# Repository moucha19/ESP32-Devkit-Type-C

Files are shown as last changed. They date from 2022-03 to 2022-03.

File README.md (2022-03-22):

ESP32 Devkit Type C
===================

## 2022 Update ([*@moucha19*](https://github.com/moucha19))

First of all, I would like to thank the original author for his work. I wanted to make this DevKit as soon as I saw it. However, there were some issues that I thought needed fixing. For example, some components were unavailable or not up-to-date. Here is a full list of my updates that all together make revision **EC**:

* CH340G was changed to CH340C to remove the need for external crystal. I also noticed that it's powered from VBUS, which according to datasheet means that the data lines will run on 5 volts. This might not kill ESP32 right away, but from what I read, it isn't good.
* I replaced MP2359 with MP2259, because the former is not recommended for new designs. JLCPCB still has MP2359s, but I wanted this update to last a while.
* USB-C connector was changed to TYPE-C-31-M-12, which I already had home. Push buttons were also changed for the same reason, but in my opinion they look good and are also pretty common.
* Inductor was replaced with currently available part 
* Some components were moved around to avoid unnecesary DRC errors
* I made pads around ESP32 larger for easier manual soldering, since I don't intend to use SMT assembly service. However, I still generated files for those who do. Use [SMT BOM](jlcpcb/bom_jlc_smt.csv) in the order to get only recommended parts (no USB-C, buttons or headers).
* Project was upgraded to Kicad 6.0

# Description

This PCB is a USB Type C enabled ESP32 development board. It is pin-compatible
with the ESP32 Devkit C but sports a slightly decreased width to fit on a
standard breadboard.  

# Features

* USB Type C
* pin-compatible with ESP32 Devkit
* fits on standard breadboard
* onboard antenna
* jumper to short USB protection diode

Furthermore this board is optimized for JLCPCB assembly, a Chinese SMT PCB
assembly service. All components on this board, except the USB Type C connector,
the push buttons and the pin headers can be assembled by them for around ~$8
including PCB manufacturing and components.

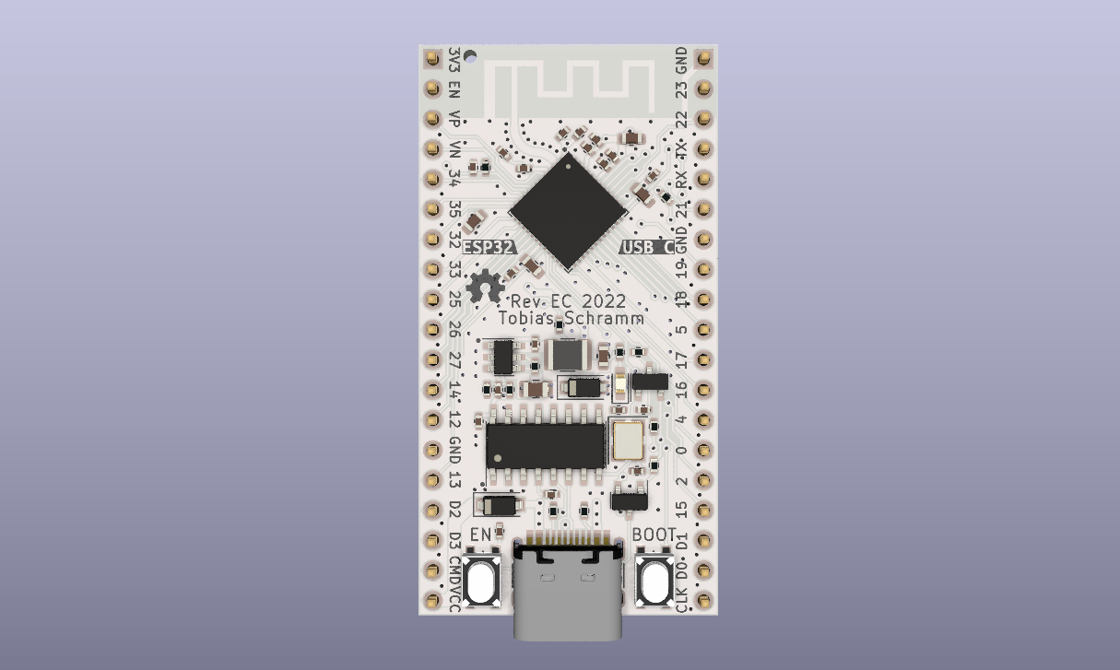
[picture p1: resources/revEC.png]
Devkit


# Assembly

There is an
[interactive HTML BOM](https://htmlpreview.github.io/?https://github.com/moucha19/ESP32-Devkit-Type-C/blob/master/docs/ibom.html)
to help you assemble the board.

Assuming you are using JLCPCB SMT assembly you will need to populate just the
following parts by hand:

| Reference  | Description | LCSC |
|---|---|---|
| J1 | USB Type C connector | [C165948](https://www.lcsc.com/product-detail/USB-Type-C_Korean-Hroparts-Elec-TYPE-C-31-M-12_C165948.html) |
| SW1, SW2 | RESET/BOOT push button | [C589212](https://lcsc.com/product-detail/Tactile-Switches_RI-SHENG-ST-1188_C589212.html) |
| J2, J3 | Pin headers | [C2337](https://lcsc.com/product-detail/Pin-Header-Female-Header_BOOMELE-Boom-Precision-Elec-2-54mm-1x40P_C2337.html) |

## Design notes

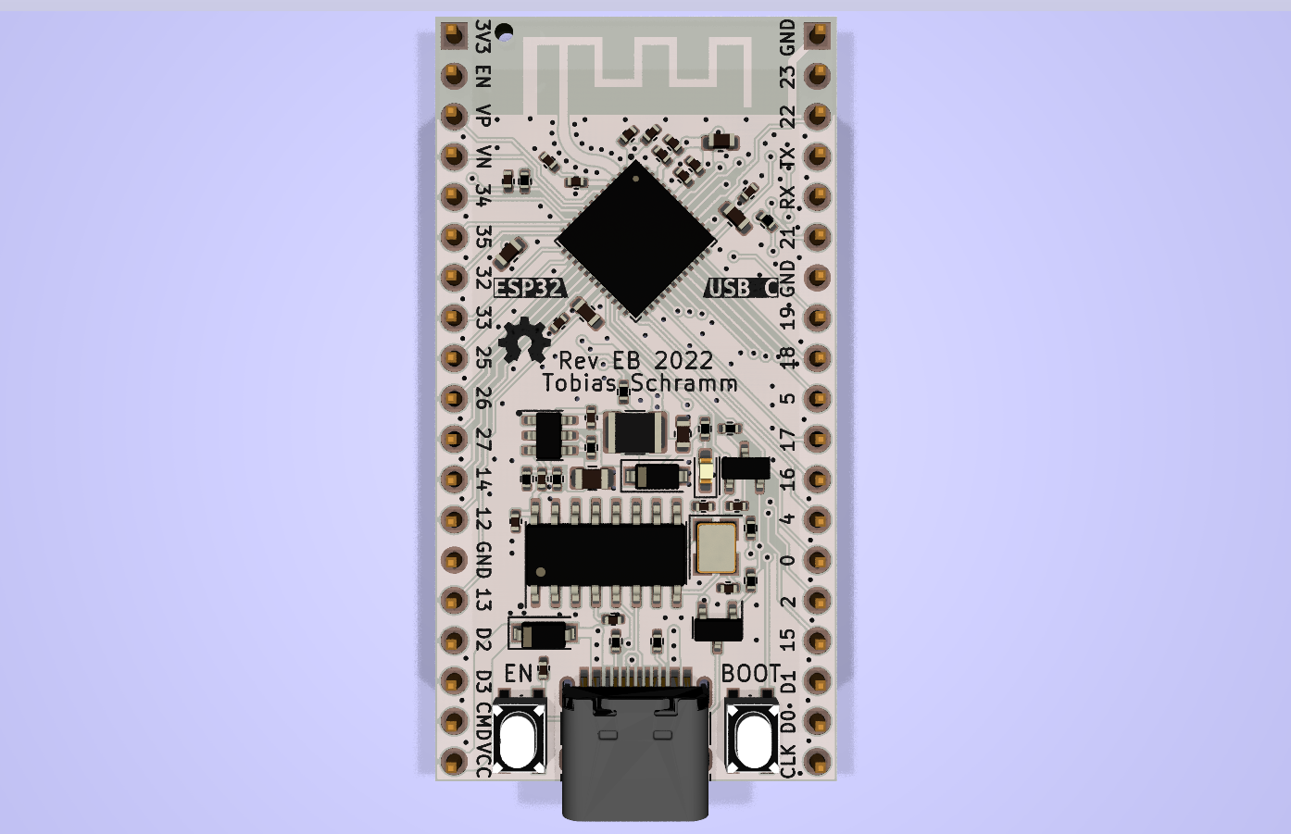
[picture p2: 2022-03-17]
resources/revEB.png

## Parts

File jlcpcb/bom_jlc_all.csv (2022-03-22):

Comment | Designator | Footprint | LCSC Part #
10 nF | C1 | Capacitor_SMD:C_0402_1005Metric | C15195
1uF | C12 | Capacitor_SMD:C_0402_1005Metric | C52923
10uF | C19,C20,C21,C22 | Capacitor_SMD:C_0402_1005Metric | C15525
22 pF | C2,C4 | Capacitor_SMD:C_0402_1005Metric | C1555
10uF | C23,C25 | Capacitor_SMD:C_0603_1608Metric | C19702
10 uF | C3 | Capacitor_SMD:C_0805_2012Metric | C15850
100 nF | C5,C6,C7,C14,C15,C16,C17,C18 | Capacitor_SMD:C_0402_1005Metric | C1525
22 uF | C8,C13,C24 | Capacitor_SMD:C_0603_1608Metric | C59461
B5819W | D1,D2 | Diode_SMD:D_SOD-123 | C8598
LED | D3 | LED_SMD:LED_0603_1608Metric_Castellated | C2286
USB_C_Receptacle_USB2.0 | J1 | Connector_USB:USB_C_Receptacle_HRO_TYPE-C-31-M-12 | C165948
Conn_01x19 | J2,J3 | Connector_PinHeader_2.54mm:PinHeader_1x19_P2.54mm_Vertical
4.7 uH | L1 | Inductor_SMD:L_1210_3225Metric | C90319
SS8050 | Q1,Q2 | Package_TO_SOT_SMD:SOT-23 | C2150
100 kR | R1,R10 | Resistor_SMD:R_0402_1005Metric | C25741
5.1 kR | R2,R3 | Resistor_SMD:R_0402_1005Metric | C25905
330 R | R4,R11,R12 | Resistor_SMD:R_0402_1005Metric | C25104
56kR | R5 | Resistor_SMD:R_0402_1005Metric | C25796
18 kR | R6 | Resistor_SMD:R_0402_1005Metric | C25762
5.1kR | R7,R8,R9 | Resistor_SMD:R_0402_1005Metric | C25905
EN | SW1 | Moucha_Primitives:SW_Push_1P1T_Vertical_3x4mm | C589212
BOOT | SW2 | Moucha_Primitives:SW_Push_1P1T_Vertical_3x4mm | C589212
MP2259 | U1 | Package_TO_SOT_SMD:SOT-23-6 | C82266
CH340C | U2 | Package_SO:SOIC-16_3.9x9.9mm_P1.27mm | C84681
ESP32-PICO-D4 | U3 | Package_ESP32:ESP32-Pico-D4-Thermal | C193707
12MHz | Y1 | Crystal:Crystal_SMD_3225-4Pin_3.2x2.5mm | C9002

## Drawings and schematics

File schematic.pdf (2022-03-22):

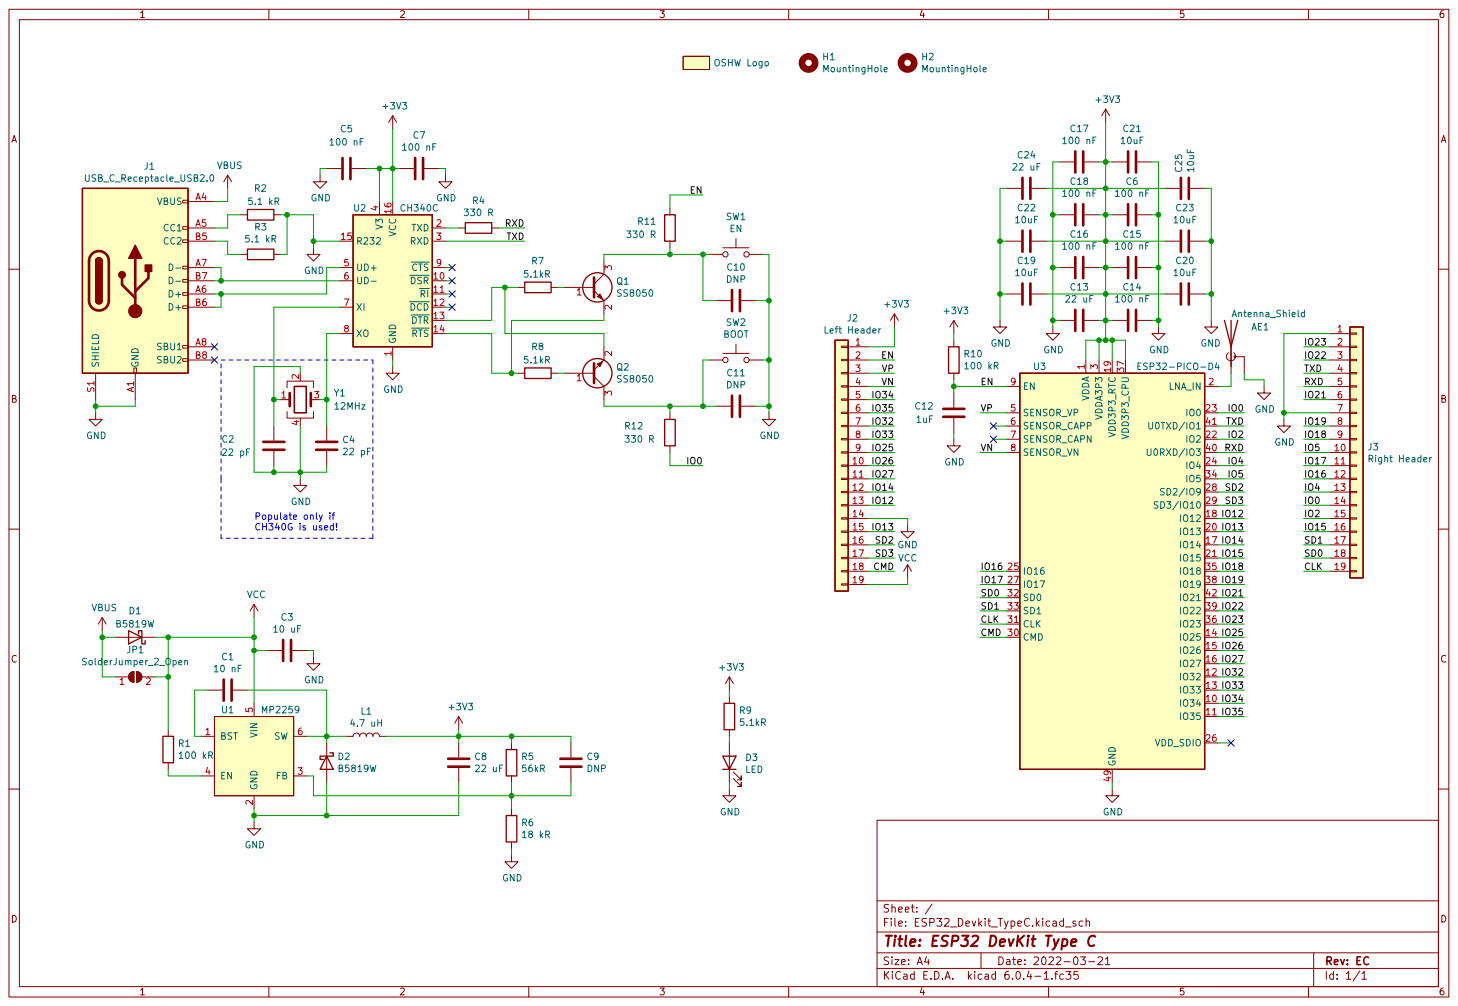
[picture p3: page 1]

4 UD+ 5 UD- 6 XI 7 XO 8 ~{CTS} 9 U2 CH340CGND

1 ~{DSR}10 ~{RI}11 ~{DCD}12 ~{DTR}13 ~{RTS}14 R232 15 VCC 16 TXD 2 RXD 3 V3

IO18 Populate only if CH340G is used!

File: ESP32_Devkit_TypeC.kicad_sch Sheet: /
Id: 1/1 Title: ESP32 DevKit Type C

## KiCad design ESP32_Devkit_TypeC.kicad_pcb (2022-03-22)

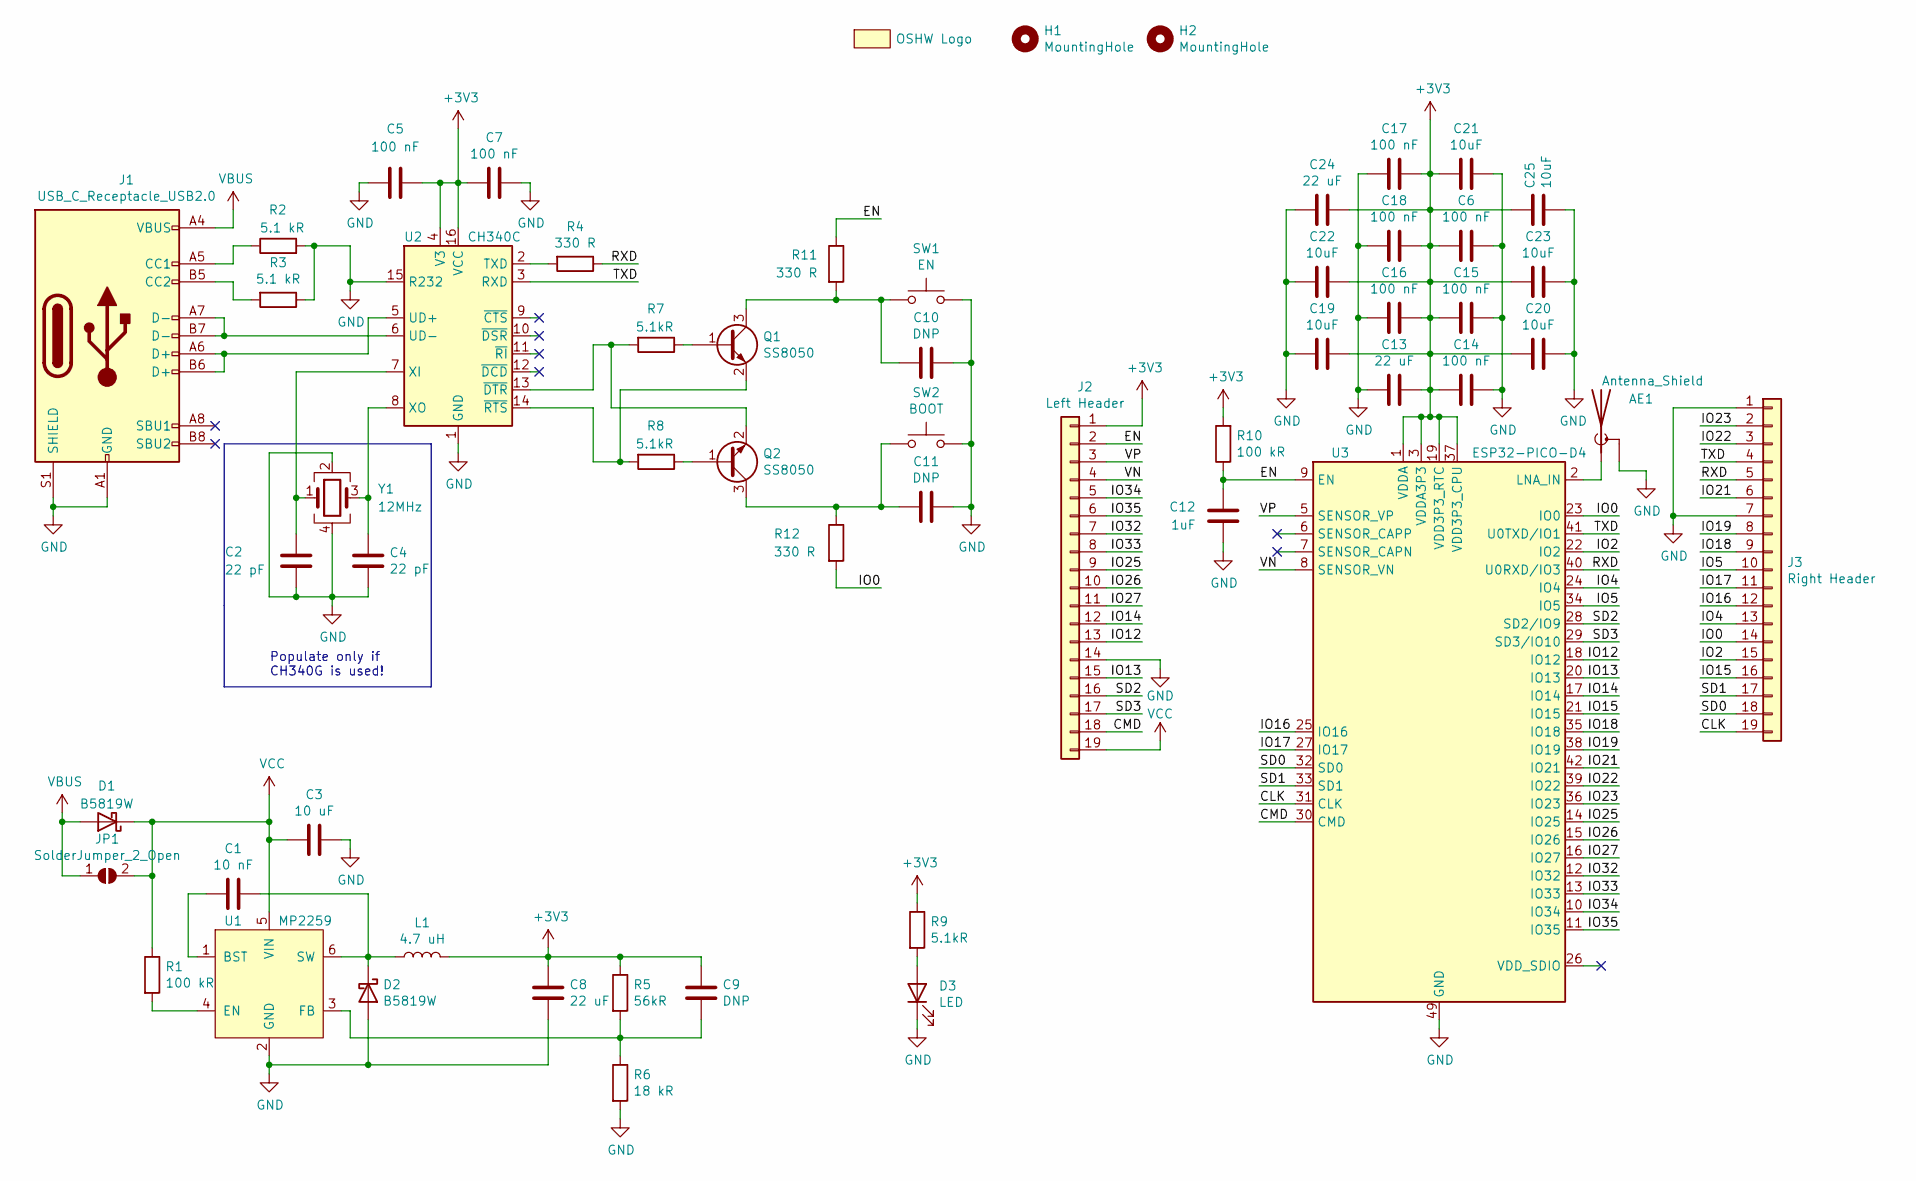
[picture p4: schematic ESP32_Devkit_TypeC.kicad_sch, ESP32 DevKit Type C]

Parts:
AE1: Antenna_Shield; Antenna_IFA_2.4GHz_meandered
C1: 10 nF; C_0402_1005Metric; LCSC C15195
C2, C4: 22 pF; C_0402_1005Metric; LCSC C1555
C3: 10 uF; C_0805_2012Metric; LCSC C15850
C5, C6, C7, C14, C15, C16, C17, C18: 100 nF; C_0402_1005Metric; LCSC C1525
C8, C13, C24: 22 uF; C_0603_1608Metric; LCSC C59461
C9, C10, C11: DNP; C_0402_1005Metric
C12: 1uF; C_0402_1005Metric; LCSC C52923
C19, C20, C21, C22: 10uF; C_0402_1005Metric; LCSC C15525
C23, C25: 10uF; C_0603_1608Metric; LCSC C19702
D1, D2: B5819W; D_SOD-123; LCSC C8598
D3: LED; LED_0603_1608Metric_Castellated; LCSC C2286
H1, H2: MountingHole; ToolingHole_JLCSMT
I2: OSHW Logo; OSHW_icon_3.3x3
J1: USB_C_Receptacle_USB2.0; USB_C_Receptacle_HRO_TYPE-C-31-M-12; LCSC C165948
J2: Left Header; PinHeader_1x19_P2.54mm_Vertical
J3: Right Header; PinHeader_1x19_P2.54mm_Vertical
JP1: SolderJumper_2_Open; SolderJumper-2_P1.3mm_Open_Pad1.0x1.5mm
L1: 4.7 uH; L_1210_3225Metric; LCSC C90319
Q1, Q2: SS8050; SOT-23; LCSC C2150
R1, R10: 100 kR; R_0402_1005Metric; LCSC C25741
R2, R3: 5.1 kR; R_0402_1005Metric; LCSC C25905
R4, R11, R12: 330 R; R_0402_1005Metric; LCSC C25104
R5: 56kR; R_0402_1005Metric; LCSC C25796
R6: 18 kR; R_0402_1005Metric; LCSC C25762
R7, R8, R9: 5.1kR; R_0402_1005Metric; LCSC C25905
SW1: EN; SW_Push_1P1T_Vertical_3x4mm; LCSC C589212
SW2: BOOT; SW_Push_1P1T_Vertical_3x4mm; LCSC C589212
U1: MP2259; SOT-23-6; LCSC C82266
U2: CH340C; SOIC-16_3.9x9.9mm_P1.27mm; LCSC C84681
U3: ESP32-PICO-D4; ESP32-Pico-D4-Thermal; LCSC C193707
Y1: 12MHz; Crystal_SMD_3225-4Pin_3.2x2.5mm; LCSC C9002

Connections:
+3V3: C5.2, C6.2, C7.2, C8.1, C9.1, C13.1, C14.2, C15.2, C16.1, C17.1, C18.1, C19.1, C20.2, C21.2, C22.1, C23.2, C24.1, C25.1, J2.1, L1.2, R5.1, R9.1, R10.2, U2.4 (V3), U2.16 (VCC), U3.1 (VDDA), U3.3 (VDDA3P3), U3.4 (VDDA3P3), U3.19 (VDD3P3_RTC), U3.37 (VDD3P3_CPU), U3.43 (VDDA), U3.46 (VDDA)
/CLK: J3.19, U3.31 (CLK)
/CMD: J2.18, U3.30 (CMD)
/EN: C12.1, J2.2, R10.1, R11.1, U3.9 (EN)
/IO0: J3.14, R12.2, U3.23 (IO0)
/IO2: J3.15, U3.22 (IO2)
/IO4: J3.13, U3.24 (IO4)
/IO5: J3.10, U3.34 (IO5)
/IO12: J2.13, U3.18 (IO12)
/IO13: J2.15, U3.20 (IO13)
/IO14: J2.12, U3.17 (IO14)
/IO15: J3.16, U3.21 (IO15)
/IO16: J3.12, U3.25 (IO16)
/IO17: J3.11, U3.27 (IO17)
/IO18: J3.9, U3.35 (IO18)
/IO19: J3.8, U3.38 (IO19)
/IO21: J3.6, U3.42 (IO21)
/IO22: J3.3, U3.39 (IO22)
/IO23: J3.2, U3.36 (IO23)
/IO25: J2.9, U3.14 (IO25)
/IO26: J2.10, U3.15 (IO26)
/IO27: J2.11, U3.16 (IO27)
/IO32: J2.7, U3.12 (IO32)
/IO33: J2.8, U3.13 (IO33)
/IO34: J2.5, U3.10 (IO34)
/IO35: J2.6, U3.11 (IO35)
/RXD: J3.5, R4.1, U3.40 (U0RXD/IO3)
/SD0: J3.18, U3.32 (SD0)
/SD1: J3.17, U3.33 (SD1)
/SD2: J2.16, U3.28 (SD2/IO9)
/SD3: J2.17, U3.29 (SD3/IO10)
/TXD: J3.4, U2.3 (RXD), U3.41 (U0TXD/IO1)
/VN: J2.4, U3.8 (SENSOR_VN)
/VP: J2.3, U3.5 (SENSOR_VP)
GND: AE1.2 (Shield), C2.2, C3.1, C4.2, C5.1, C6.1, C7.1, C8.2, C10.1, C11.1, C12.2, C13.2, C14.1, C15.1, C16.2, C17.2, C18.2, C19.2, C20.1, C21.1, C22.2, C23.1, C24.2, C25.2, D2.2 (A), D3.1 (K), J1.A1 (GND), J1.A12 (GND), J1.B1 (GND), J1.B12 (GND), J1.S1 (SHIELD), J2.14, J3.1, J3.7, R2.2, R3.1, R6.2, SW1.2, SW2.2, U1.2 (GND), U2.1 (GND), U2.15 (R232), U3.49 (GND), Y1.2, Y1.4
unnamed: AE1.1 (A), U3.2 (LNA_IN)
unnamed: C1.1, D2.1 (K), L1.1, U1.6 (SW)
unnamed: C1.2, U1.1 (BST)
unnamed: C2.1, U2.7 (XI), Y1.1
unnamed: C4.1, U2.8 (XO), Y1.3
unnamed: C9.2, R5.2, R6.1, U1.3 (FB)
unnamed: C10.2, Q1.3 (C), R11.2, SW1.1
unnamed: C11.2, Q2.3 (C), R12.1, SW2.1
unnamed: D3.2 (A), R9.2
unnamed: J1.A5 (CC1), R2.1
unnamed: J1.A6 (D+), J1.B6 (D+), U2.5 (UD+)
unnamed: J1.A7 (D-), J1.B7 (D-), U2.6 (UD-)
unnamed: J1.B5 (CC2), R3.2
unnamed: Q1.1 (B), R7.1
unnamed: Q1.2 (E), R8.2, U2.14 (~RTS)
unnamed: Q2.1 (B), R8.1
unnamed: Q2.2 (E), R7.2, U2.13 (~DTR)
unnamed: R1.2, U1.4 (EN)
unnamed: R4.2, U2.2 (TXD)
VBUS: D1.2 (A), J1.A4 (VBUS), J1.A9 (VBUS), J1.B4 (VBUS), J1.B9 (VBUS), JP1.1 (A)
VCC: C3.2, D1.1 (K), J2.19, JP1.2 (B), R1.1, U1.5 (VIN)

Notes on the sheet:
Populate only if CH340G is used!

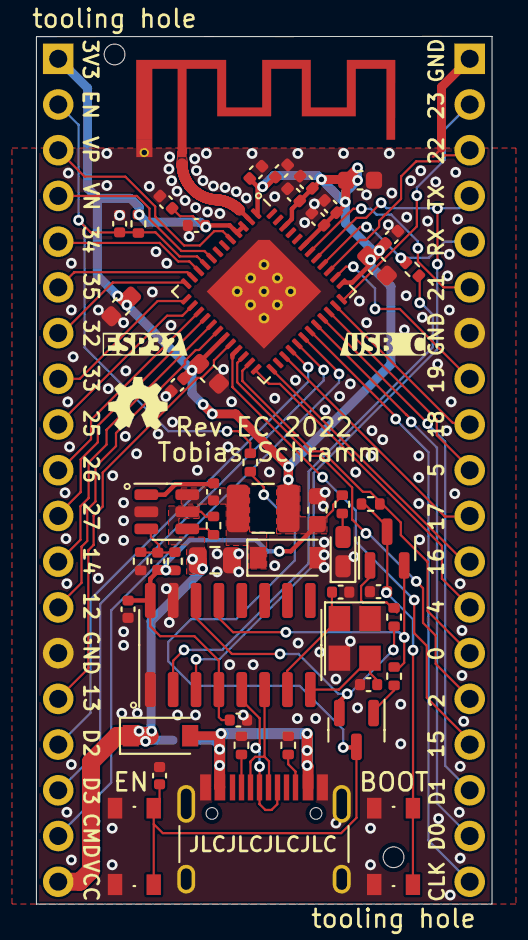
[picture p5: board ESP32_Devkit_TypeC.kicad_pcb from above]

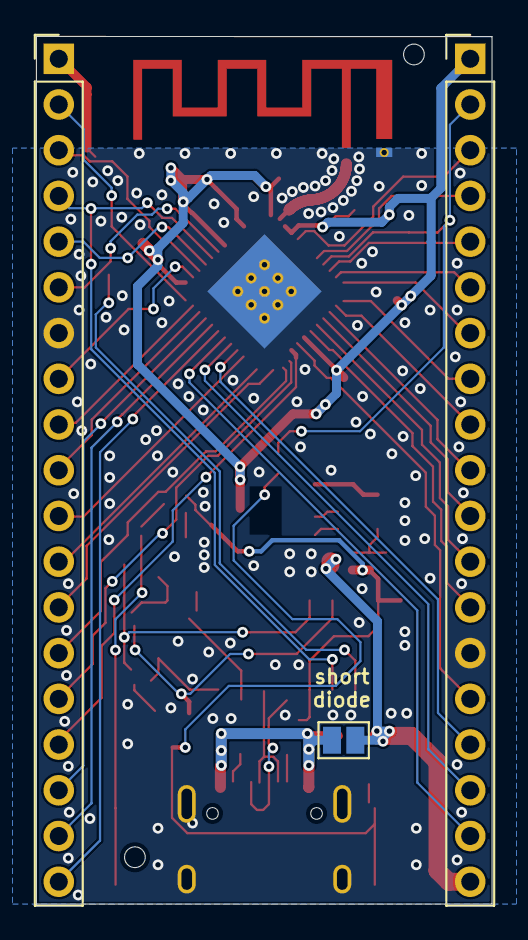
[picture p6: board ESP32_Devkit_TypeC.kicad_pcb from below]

Board: 2 copper layers, 25.3 x 48.2 mm, 59 parts (3 on the bottom side), 56 nets.

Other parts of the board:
kibuzzard-62337F52: G***; kibuzzard-62337F52
kibuzzard-62337F79: G***; kibuzzard-62337F79

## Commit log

2022-03-12 Migrated project to Kicad 6.0, removed unnecessary files
    [ESP32_Devkit_TypeC.kicad_pcb, ESP32_Devkit_TypeC.kicad_sch, ESP32_Devkit_TypeC.sch]
2022-03-13 Updated DC-DC convertor, fixed CH340G Vout
    I changed switching regulator to MP2259, because MP2359 is not recommended for new designs and is therefore more futureproof.
    Resistor values was also changed to lower the voltage from 3.5V to 3.33V.
    I also changed USB-C type to TYPE-C-31-M-12, because I have it :) It also seems to be more popular and I saw many compatible clones on Aliexpress for example.
    CH340G was set to operate with 5V signals, which isn't good for ESP, so I changed it. I also changed the part to CH340C to avoid using external crystal (which will be optional for CH340G compatibility).
    [ESP32_Devkit_TypeC.kicad_sch]
2022-03-13 Changed 4.7uF inductor part
    [ESP32_Devkit_TypeC.kicad_sch]
2022-03-13 Updated footprints, reconnected CH340C
    [ESP32_Devkit_TypeC.kicad_pcb, ESP32_Devkit_TypeC.kicad_sch]
2022-03-13 Changed button type, DRC fixes
    [ESP32_Devkit_TypeC.kicad_pcb, ESP32_Devkit_TypeC.kicad_sch]
2022-03-13 updated documentation
    [ESP32_Devkit_TypeC.kicad_pcb, ESP32_Devkit_TypeC.kicad_sch, ESP32_Devkit_TypeC_bom_jlc.csv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]
2022-03-13 Fixed component rotation
    [ESP32_Devkit_TypeC.kicad_pcb, ESP32_Devkit_TypeC.kicad_sch, bom_jlc_smt.csv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]
2022-03-13 Updated readme, fixed default BOM view
2022-03-17 Rev EB serial transciever bugfix, component upgrade
    [ESP32_Devkit_TypeC.kicad_pcb, ESP32_Devkit_TypeC.kicad_sch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]
2022-03-22 Rev EC
    updated ESP32 footprint based on datasheet, minor silkscreen fixes
    [ESP32_Devkit_TypeC.kicad_pcb, ESP32_Devkit_TypeC.kicad_sch, bom_jlc_all.csv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]
